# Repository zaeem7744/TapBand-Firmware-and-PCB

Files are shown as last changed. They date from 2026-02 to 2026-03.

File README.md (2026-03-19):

# :watch: TapBand -- MQTT IoT Wearable Device (In Mass Production)







A compact **5cm x 3cm** battery-powered wearable IoT device with MQTT real-time communication, OLED display, WS2812B LEDs, vibration motor, and deep-sleep power optimization. Built for a commercial security application for an Ireland-based startup -- **currently in mass production**.

> See also: [TapBand Web Dashboard](https://github.com/zaeem7744/TapBand-Web-Dashboard)

---

## :camera: PCB Design (Altium Designer)

### Front -- ESP32 Module + OLED Display
Custom-designed compact PCB featuring ESP32 Wi-Fi/BLE module and SSD1306 OLED display.

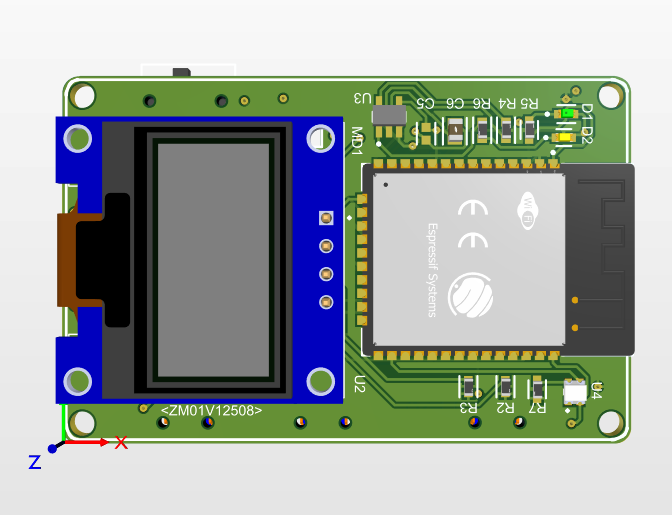
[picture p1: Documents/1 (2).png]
TapBand PCB Front


### Back -- Full Component Layout
Battery connector, USB charging, 4 navigation buttons (SW1-SW4), vibration motor driver, WS2812B LED driver, and SMD power management.

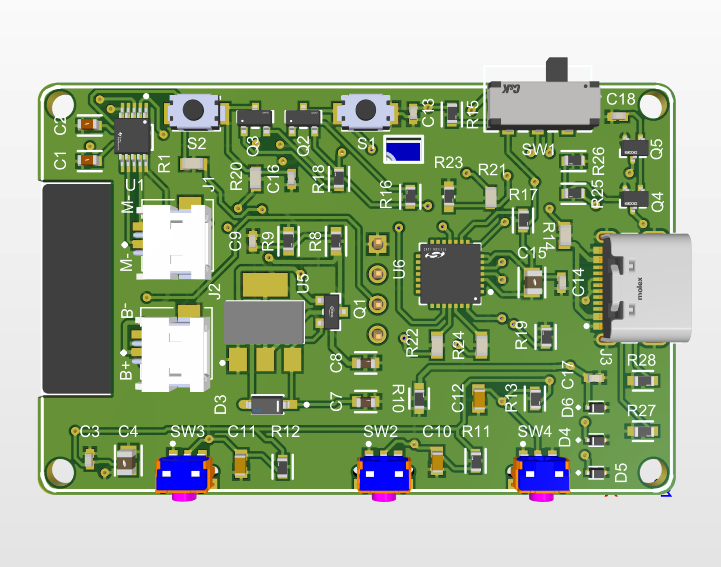
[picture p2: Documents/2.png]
TapBand PCB Back


### PCB Layout -- Altium Designer
Multi-layer PCB routing optimized for compact form factor and RF performance.

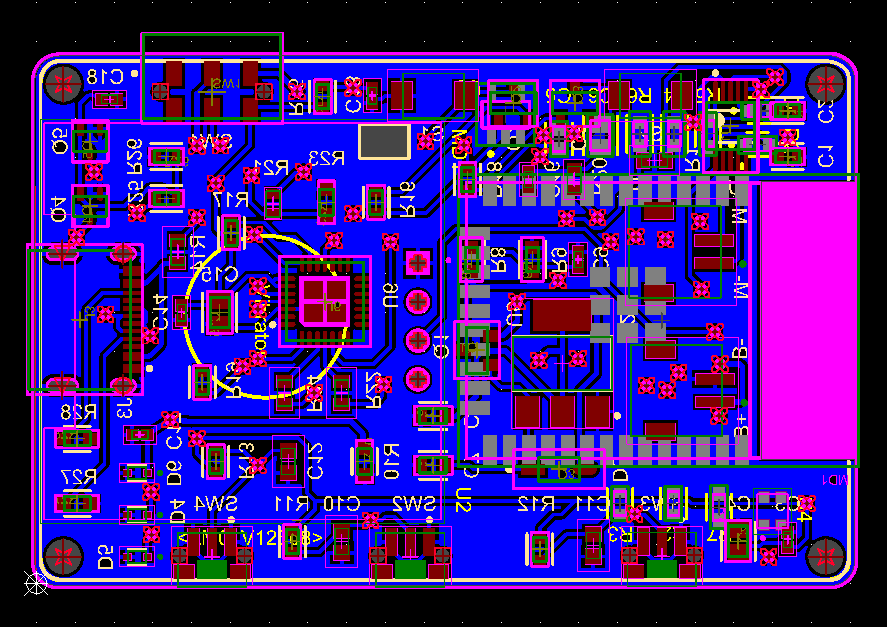
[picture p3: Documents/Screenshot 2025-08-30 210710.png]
PCB Layout


---

## :zap: Key Highlights

- **Ultra-Compact: 5cm x 3cm** -- production-optimized PCB designed in Altium Designer
- **Currently in mass production** for commercial security applications
- **MQTT real-time communication** via HiveMQ Cloud broker
- **Deep-sleep optimization** for extended battery life
- **Wi-Fi provisioning** -- hotspot-based setup, no hardcoded credentials
- **Custom PCB with Gerber files** -- production-ready design
- **Full ecosystem** -- firmware + PCB + web dashboard + Flask backend

---

## :wrench: Features

| Feature | Description |
|---|---|
| **OLED Display** | SSD1306 menu-driven interface with navigation buttons |
| **MQTT Communication** | Bidirectional real-time messaging via HiveMQ Cloud |
| **Deep Sleep** | Aggressive power saving for battery longevity |
| **Wi-Fi Provisioning** | Hotspot-based initial setup |
| **WS2812B LEDs** | Addressable RGB LED indicators for visual alerts |
| **Vibration Motor** | Haptic feedback for notifications |
| **4 Navigation Buttons** | Physical UI for menu navigation and actions |
| **USB Charging** | Micro-USB/USB-C connector for battery charging |
| **Admin Dashboard** | Real-time subscription management via web panel |
| **Flask Backend** | Server-side MQTT relay and device management |

---

## :file_folder: Project Structure

```
TapBand-Firmware-and-PCB/
|-- TapBand_Main/              # Main production firmware
|-- TapBand_Design/            # Altium Designer PCB project files
|-- Documents/                 # PCB renders, screenshots, schematics
|-- MQTT/                      # MQTT communication module
|-- OLED_MQTT/                 # OLED + MQTT integration
|-- OLED_INTERFAACE/           # OLED display driver
|-- WIFI_PROVISIONIG_MQTT_OLED/ # Wi-Fi provisioning system
|-- PowerSave_AlertBand_Test/  # Deep-sleep power profiling
|-- WS2812_Test/               # LED strip testing
|-- Board_Vibrator_Test/       # Vibration motor testing
|-- Sync_Mqtt_Hive/            # HiveMQ broker sync module
+-- Web App/                   # Flask backend + MQTT dashboard
    |-- mqtt_dashboard/        # Real-time MQTT monitoring
    +-- tapband_server/        # Flask backend for device management
```

---

## :hammer_and_wrench: Tech Stack

| Component | Technology |
|---|---|
| **MCU** | ESP32 (Espressif Systems) |
| **Language** | C/C++ (PlatformIO) |
| **Communication** | MQTT (HiveMQ Cloud), Wi-Fi |
| **Display** | SSD1306 OLED (I2C) |
| **LEDs** | WS2812B addressable RGB |
| **PCB Design** | Altium Designer |
| **Backend** | Flask (Python) + MQTT relay |
| **Dashboard** | [React + TypeScript](https://github.com/zaeem7744/TapBand-Web-Dashboard) |
| **Power** | LiPo battery + deep-sleep optimization |

---

## :bust_in_silhouette: Author

**Muhammad Zaeem Sarfraz** -- Electronics & IoT Hardware Engineer

- :link: [LinkedIn](https://www.linkedin.com/in/zaeemsarfraz7744/)
- :email: Zaeem.7744@gmail.com
- :earth_africa: Vaasa, Finland

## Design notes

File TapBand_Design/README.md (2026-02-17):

# TapBand_Design

Altium Designer project for the band’s electronics: MCU, power, haptics, display, and connectors.

## Open
- `TapBand/TapBand.PrjPcb` in Altium Designer

## What’s inside
- Schematics (`*.SchDoc`):
  - Main: ESP32 and core nets
  - I2C_OLED_DRV2605: OLED and haptics driver
  - VOLTAGE_REGULATOR: power tree and battery input
  - USB_UART: programming and debug
  - Menu_Navigators: buttons/encoder
- PCB: `TapBand.PcbDoc`
- Outputs: `Project Outputs for TapBand/` → Gerbers, drills, BOM, pick‑and‑place; plus zipped packs
- Logs: ECO, DRC, compilation logs under `Project Logs for TapBand/`
- CAM: example CAMtastic session in `TapBand/CAM/`

## Fabrication checklist
- Verify board stackup with your fab; ensure soldermask openings on the haptic footprint are correct
- Check mounting and keepouts for the actuator and OLED
- Use the provided pick/place and BOM CSVs; confirm part numbers for the DRV2605 variant and OLED connector pitch

## Notes
- If you change net names or variants, regenerate outputs from the OutJob to keep files consistent

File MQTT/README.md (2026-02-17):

# MQTT

Tiny sketch to sanity‑check Wi‑Fi + MQTT connectivity on ESP32.

## Use
- Open `MQTT.ino`
- Set your Wi‑Fi SSID/password and broker host/port/topic
- Flash and open Serial Monitor (115200). You should see connect logs and a periodic publish every 5s

## Tips
- Use a unique client ID per device to avoid broker kicks
- Public brokers are for testing; for real use, switch to a private/TLS broker and don’t hardcode secrets in source

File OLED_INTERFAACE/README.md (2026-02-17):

# OLED_INTERFAACE

OLED rendering experiments to validate fonts/layout on 128x64 displays.

## Build
- Libraries: Adafruit GFX, Adafruit SSD1306
- I2C: SDA 21, SCL 22, address 0x3C (common); adjust if your module differs

## Tips
- If the screen is blank, try lowering I2C frequency, confirm address with an I2C scanner, and check for adequate 3.3V current

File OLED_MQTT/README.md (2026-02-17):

# OLED_MQTT

Prototype: rotary encoder menu + OLED UI + MQTT publish/subscribe.

## Features
- Home screen with battery and Wi‑Fi indicators; shows last alert for ~8s
- Menu: Assist Mode, Alert Mode, Settings, Back (encoder to navigate, press to select)
- MQTT subscribe to band/alert; publishes ASSIST/ALERT on action

## Build
- Board: ESP32, OLED on I2C (SDA 21, SCL 22, 0x3C)
- Encoder pins: CLK 34, DT 35, SW 32 (INPUT_PULLUP)
- Libraries: Adafruit GFX, Adafruit SSD1306, WiFi, PubSubClient

## Notes
- Replace hardcoded SSID/password with your own before flashing
- For smoother UI, debounce the encoder and avoid heavy blocking delays (a few remain in this prototype)

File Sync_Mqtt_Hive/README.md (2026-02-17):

# Sync_Mqtt_Hive

Prototype for synchronizing with HiveMQ topics.

## Notes
- Edit broker/topic credentials, then verify message round‑trip and latency
- Useful for testing subscription/publish ordering and retained messages

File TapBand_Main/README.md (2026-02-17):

# TapBand_Main

Feature‑complete ESP32 firmware for the band: OLED UI, menu system, Wi‑Fi provisioning via captive portal, MQTT alerts, and haptics through DRV2605.

## Hardware/pins (defaults)
- OLED I2C: SDA 21, SCL 22, addr 0x3C
- Buttons: UP 27, DOWN 34, SELECT 35 (INPUT_PULLUP)
- Vibration: EN 33 (DRV2605 on I2C)
- Battery sense: ADC 19 via divider R1=220k, R2=100k
- Built‑in LED used for alert blink feedback

## Libraries
- Adafruit GFX, Adafruit SSD1306, Adafruit DRV2605
- PubSubClient (MQTT), WiFi, WebServer, Preferences

## Build (Arduino IDE)
1) Board: “ESP32 Dev Module” (or your ESP32 variant)
2) Install libraries above from Library Manager
3) Open `TapBand_Main.ino` and flash; Serial Monitor: 115200 baud
4) If first boot has no Wi‑Fi creds, use Menu → Settings → Wi‑Fi Setup

## Menu map and flow
- Home → shows battery, Wi‑Fi bars, and last alert for ~8s
- Main Menu: Alert Mode, Assist Mode, Normal Mode, Settings, Back
- Settings: Wi‑Fi Setup (starts AP + portal), Reset Wi‑Fi, Back
- In modes, pressing SELECT publishes the corresponding MQTT message and returns Home

## Wi‑Fi provisioning (captive portal)
- When Wi‑Fi Setup is selected, device starts AP TapBand_<DEVICE_ID> and a minimal web server
- Open the root page, submit SSID/password; device stores them in NVS (Preferences) and restarts
- Hotspot auto‑times‑out after 180s (WIFI_HOTSPOT_TIMEOUT)

## MQTT
- Defaults: server broker.hivemq.com, port 1883, topic band/alert (see Config.h)
- Subscribes to band/alert; publishes NORMAL/ALERT/ASSIST depending on mode
- Tip: in production, change to your broker, use TLS, and unique client IDs; consider Last‑Will and retained metadata

## Battery model
- Voltage: Vadc = raw/4095*3.3V; Vbat = Vadc*(R1+R2)/R2 + VOLTAGE_OFFSET
- Percentage mapping clamps between BATTERY_EMPTY (3.7V) and BATTERY_FULL (4.2V). Adjust these and VOLTAGE_OFFSET per your cells/board.

## Haptics
- DRV2605 library 1, INTTRIG mode. Effects are mapped in `Vibration_System.h`:
  - Wi‑Fi connect/disconnect, menu navigate/back/screen change, confirmations, alerts, low battery, hotspot start
- Start with short effects to verify actuator polarity and mounting

## Extending
- New menu items: add labels to Menu_System.cpp, handle in switch, and implement action.
- New MQTT topics: update Config.h and WiFi_MQTT.cpp callback/publish sites.
- UI: tweak Display_Functions.cpp; keep draw calls minimal per frame to avoid flicker.

## Troubleshooting
- “SSD1306 allocation failed”: power/I2C wiring or wrong address
- No MQTT: check Wi‑Fi status, broker reachability, and client.loop() in the main loop
- ADC jumps: add a small RC filter, sample average (already 5x), and re‑tune VOLTAGE_OFFSET

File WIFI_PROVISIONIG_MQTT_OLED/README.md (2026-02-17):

# WIFI_PROVISIONIG_MQTT_OLED

Minimal demo showing captive portal provisioning, MQTT connectivity, and a compact OLED UI.

## What it does
- Shows Home with battery and Wi‑Fi bars
- Main Menu → Settings → Wi‑Fi Setup starts AP TapBand_<ID> and hosts a simple form at “/”
- POST to "/connect" saves SSID/password to Preferences and restarts
- Hotspot timeout: 180s; display shows countdown

## Build
- Board: ESP32 Dev Module
- Libraries: Adafruit GFX, Adafruit SSD1306, WiFi, PubSubClient, WebServer, Preferences
- Pins: SDA 21, SCL 22, Encoder CLK/DT/SW 34/35/32 (if used), OLED 0x3C

## MQTT
- Default: broker.hivemq.com, topic band/alert; change for your broker/security

## Tips
- If the portal doesn’t load, ensure you are connected to the device AP, not a LAN with captive DNS
- After provisioning, the device returns to HOME automatically; use Reset Wi‑Fi to clear creds

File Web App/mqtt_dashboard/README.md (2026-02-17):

# mqtt_dashboard

Flask + MQTT dashboard to manage “shops” and “bands”, visualize online/offline status, and toggle per‑band alerts.

## Stack and layout
- Flask app: `app.py`
- Templates: `templates/index.html`, `templates/shop.html`
- SQLite DB: `bands.db` with tables shops(id, shop_name, start_date, end_date) and bands(id, band_name, shop_id)
- MQTT: paho‑mqtt client thread for subscriptions and control publishing

## Install and run
- Python 3.x
- pip install flask paho-mqtt
- Configure broker in `app.py`:
  - Host/port: mqtt_client.connect(...)
  - TLS CA path: mqtt_client.tls_set("<path-to-ca.crt>")
  - Username/password: mqtt_client.username_pw_set("<user>", "<pass>")
- Initialize DB and start: python app.py → http://localhost:5000

## MQTT topics
- Subscribes: tapband/# and tapband/alerts
- Publishes control: tapband/control/{shop}/{band} with payload "enable" or "disable"
- Device status feed (expected): tapband/{shop}/Band_XXX with JSON payloads like {"uptime": "HH:MM"}
- An offline checker thread marks devices offline if no message for >10s; subscription state updates every 5s

## Pages
- Dashboard “/”: create shops, view subscription window, counts of total/online bands
- Shop “/shop/<id>”: list bands, toggle alert (publishes control topic), add/delete bands

## Notes and tips
- Keep TLS CA path valid for your broker; if you use a public broker without TLS, remove tls_set and change port
- For production: run gunicorn/uwsgi behind a reverse proxy; move credentials to environment variables
- The web UI is intentionally minimal; extend templates for richer views (signal strength, last seen, etc.)

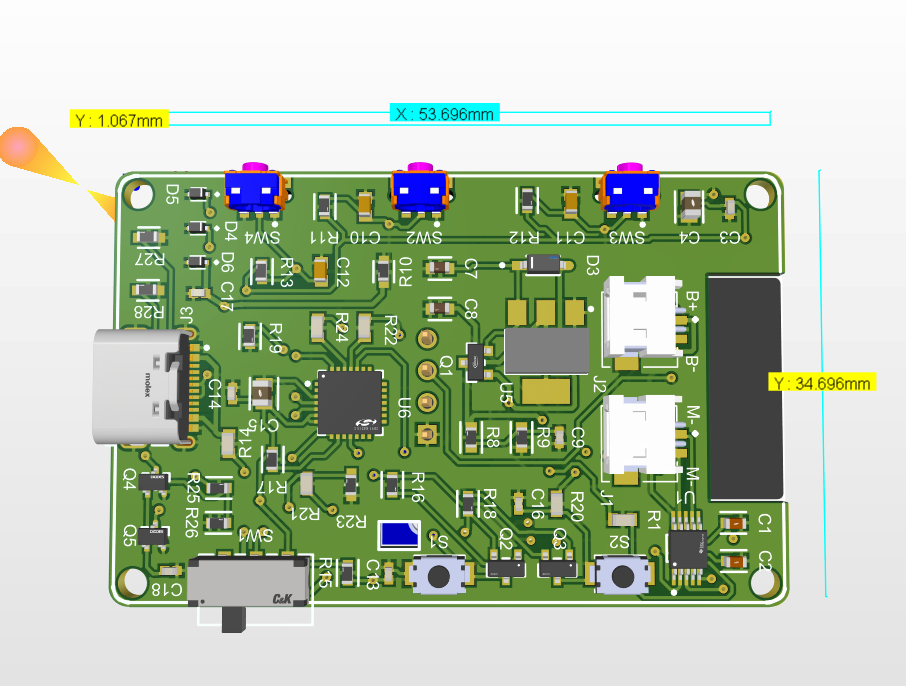
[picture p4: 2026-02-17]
Documents/Screenshot 2025-08-30 212027.png

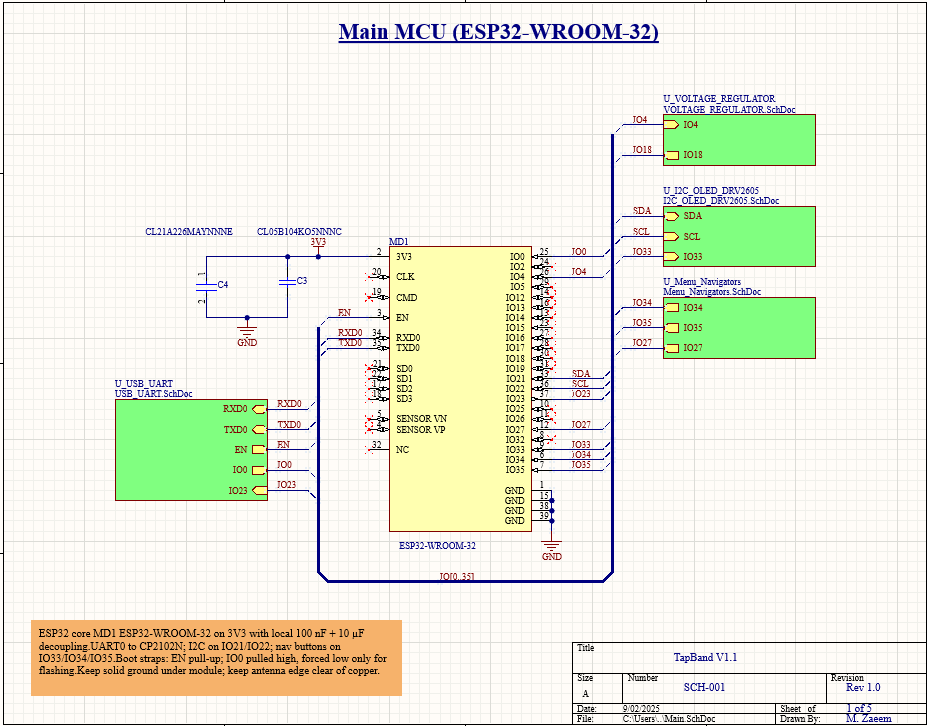
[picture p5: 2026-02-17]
Documents/Screenshot 2025-09-02 193534.png

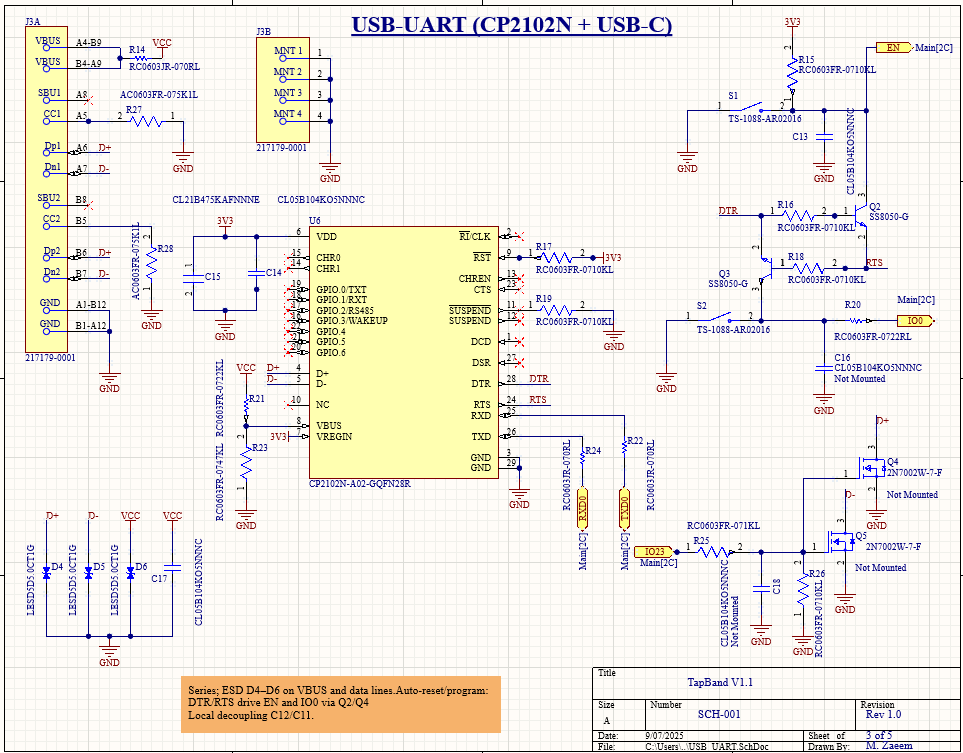
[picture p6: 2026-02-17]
Documents/Screenshot 2025-09-07 011952.png

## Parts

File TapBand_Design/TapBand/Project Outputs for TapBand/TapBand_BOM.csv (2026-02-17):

Comment | Description | Designator | Footprint | Supplier | Supplier Part Number | Quantity
CL10B105KA8NNNC | CAP CER 1UF 25V X7R 0603 | C1, C2 | FP-CL10-IPC_C | LCSC | C29936 | 2
CL05B104KO5NNNC | Chip Capacitor, 100 nF, +/- 10%, 16 V, -55 to 125 degC, 0402 (1005 Metric), RoHS, Tape and Reel | C3, C9, C13, C14, C16, C17, C18 | CAPC1050X55X23ML05T13 | LCSC | C1525 | 7
CL21A226MAYNNNE | CL21 Series 0805 22uF 25V ±20% Tolerance X5R Multilayer Ceramic Chip Capacitor | C4 | FP-CL21-IPC_C | LCSC | C602037 | 1
GRM188R61E475KE11D | Chip Multilayer Ceramic Capacitors for General Purpose, 0603, 4.7uF, X5R, 15%, 10%, 25V | C5 | FP-GRM188-0_15-IPC_C | LCSC | C90057 | 1
CL21B475KAFNNNE | CL21 Series 0805 4.7uF 25V ±10% Tolerance X7R Multilayer Ceramic Chip Capacitor | C6, C15 | FP-CL21-IPC_C | LCSC | C98195 | 2
GRM188R61E106MA73D | Chip Multilayer Ceramic Capacitors for General Purpose, 0603, 10uF, X5R, 15%, 20%, 25V | C7, C8 | FP-GRM188-0_2-MFG | LCSC | C91606 | 2
GRM188R71H104KA93D | Chip Capacitor, 0.1 uF, +/- 10%, 50 V, -55 to 125 degC, 0603 (1608 Metric), RoHS, Tape and Reel | C10, C11, C12 | CAPC1608X90X35ML10T15 | LCSC | C77055 | 3
LTST-C190GKT | LED GREEN CLEAR CHIP SMD | D1 | FP-LTST-C190GKT-MFG | LCSC | C125093 | 1
LTST-C191KSKT | LED YELLOW CLEAR SMD | D2 | FP-LTST-C191KSKT-MFG | LCSC | C125100 | 1
1N5819HW-7-F | DIODE SCHOTTKY 40V 1A SOD123 | D3 | FP-SOD123-IPC_A | LCSC | C82544 | 1
LESD5D5.0CT1G | Transient Voltage Suppressors for ESD Protection | D4, D5, D6 | TVS_LESD5D5.0CT1G | LCSC | C383211 | 3
S2B-ZR-SM4A-TF(LF)(SN) | Connector Header Surface Mount, Right Angle 2 position 0.059 (1.50mm) | J1, J2 | JST_S2B-ZR-SM4A-TF(LF)(SN) | LCSC | C265329 | 2
217179-0001 | CONN RCP USB2.0 TYP C 24P SMD RA | J3 | FP-2171790001-MFG | LCSC | C3197684 | 1
ESP32-WROOM-32 | RX TXRX MOD WIFI SURFACE MOUNT | MD1 | FP-ESP32-WROOM-32-MFG | LCSC | C701343 | 1
IRLML6402TRPBF | MOSFET P-CH 20V 3.7A SOT-23 | Q1 | FP-Micro3-MFG | LCSC | C2593 | 1
SS8050-G | NPN TRANSISTOR 1.5A 40V SOT-23 R | Q2, Q3 | FP-SS8050-G-MFG | LCSC | C164886 | 2
2N7002W-7-F | MOSFET N-CH 60V 115MA SOT323 | Q4, Q5 | FP-SOT323-IPC_C | LCSC | C139444 | 2
RC0603JR-070RL | Chip Resistor, 0 Ohm, +/- 5%, 0.1 W, -55 to 155 degC, 0603 (1608 Metric), RoHS, Tape and Reel | R1, R14, R22, R24 | RESC1608X55X25ML10T15 | LCSC | C95177 | 4
RC0603FR-0710KL | RES 10K OHM 1% 1/10W 0603 | R2, R3, R11, R12, R13, R15, R16, R17, R18, R19, R26 | FP-RC0603-0_55-IPC_C | LCSC | C98220 | 11
AC0603FR-072KL | RES 2kO 1.00% 0.1W 0603 | R4, R6 | FP-AC0603-IPC_B | LCSC | C125933 | 2
AC0603FR-075K1L | RES 5.1KO 1.00% 0.1W 0603 | R5, R7, R27, R28 | FP-AC0603-MFG | LCSC | C125891 | 4
RC0603FR-07200KL | RES SMD 200K OHM 1% 1/10W 0603 | R8, R9 | FP-RC0603-0_55-IPC_B | LCSC | C105574 | 2
AC0603FR-07100KL | RES 100KO 1.00% 0.1W 0603 | R10 | FP-AC0603-MFG | LCSC | C116674 | 1
RC0603FR-0722RL | Chip Resistor, 22 Ohm, +/- 1%, 0.1 W, -55 to 155 degC, 0603 (1608 Metric), RoHS, Tape and Reel | R20 | RESC1608X55X25NL10T15 | LCSC | C107701 | 1
RC0603FR-0722KL | Chip Resistor, 22 KOhm, +/- 1%, 0.1 W, -55 to 155 degC, 0603 (1608 Metric), RoHS, Tape and Reel | R21 | RESC1608X55X25LL10T15 | LCSC | C114065 | 1
RC0603FR-0747KL | RES SMD 47K OHM 1% 1/10W 0603 | R23 | FP-RC0603FR-0747KL-MFG | LCSC | C105579 | 1
RC0603FR-071KL | RES 1K OHM 1% 1/10W 0603 | R25 | FP-RC0603-0_55-IPC_C | LCSC | C22548 | 1
TS-1088-AR02016 | 50mA 4mm 100MÎ© 100,000 Times 12V 160gf 3mm 2mm Round Button Vertical welding SPST SMD Tactile Switches ROHS | S1, S2 | SW_TS-1088-AR02016 | LCSC | C720477 | 2
JS202011JAQN | SWITCH SLIDE DPDT 300MA 6V | SW1 | FP-JS202011JAQN-MFG | LCSC | C221664 | 1
SKRTLAE010 | Side Push Type, 250 V, -40 to 90 degC, 3-Pin SMD, RoHS, Tape and Reel | SW2, SW3, SW4 | ALPS-SKRTLAE010_V | LCSC | C110293 | 3
DRV2605LDGSR | IC MOTOR DRIVER 2V-5.5V 10VSSOP | U1 | FP-DGS0010A-MFG | LCSC | C527464 | 1
DM-OLED096-636 | 0.96â€� 128 X 64 MONOCHROME GRAPHIC OLED DISPLAY MODULE - I2C | U2 | MODULE_DM-OLED096-636 | LCSC | C5248080 | 1
MCP73831T-2ACI/OT | IC CONTROLLR LI-ION 4.2V SOT23-5 | U3 | FP-C04-091-OT-MFG | LCSC | C424093 | 1
WS2812C-2020 | Intelligent control LED integrated light source | U4 | LED_WS2812C-2020 | LCSC | C2976072 | 1
NCP1117ST33T3G | Low-Dropout Positive Fixed Voltage Regulator, 1 A, 3.3 V Output Voltage, 0 to 125 degC, 4-Pin SOT-223 (318H-01), Pb-Free, Tape and Reel | U5 | ONSC-SOT-223-4-318H-01_A_V | LCSC | C26537 | 1
CP2102N-A02-GQFN28R | IC USB TO UART BRIDGE QFN28 | U6 | FP-CP2102N-A02-GQFN28R-MFG | LCSC | C964632 | 1

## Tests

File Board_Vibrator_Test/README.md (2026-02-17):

# Board_Vibrator_Test

Validate the DRV2605 haptic driver and actuator wiring.

## Build
- Board: ESP32
- Libraries: Adafruit DRV2605, Wire
- I2C: SDA 21, SCL 22; ensure 3.3V and GND connected; typical DRV2605 addr 0x5A

## What to look for
- Short clicks/buzzes for different effects; if it feels weak or inverted, re‑mount the actuator or try other effects
- If nothing happens: check I2C wiring, selectLibrary(1), and INTTRIG mode

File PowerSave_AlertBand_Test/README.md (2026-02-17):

# PowerSave_AlertBand_Test

Experiments around lowering power while preserving alert behavior.

## Ideas tested
- Short display update windows, longer sleep between loops
- Minimizing Wi‑Fi duty cycle; reconnect only when needed
- Visual cue on wake, then resume sleep

## Measure
- Use a USB power meter or shunt to compare baseline vs. optimized loops

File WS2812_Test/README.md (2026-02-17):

# WS2812_Test

Quick WS2812/NeoPixel test.

## Build
- Board: ESP32
- Library: Adafruit NeoPixel (if used in the sketch)
- Define LED pin and count for your setup; ensure a proper 5V rail and a level‑shifted data line if the run is long

## Notes
- Add a 330–470Ω series resistor on DIN and a large 5V bulk cap (>1000µF) for stability on long strips

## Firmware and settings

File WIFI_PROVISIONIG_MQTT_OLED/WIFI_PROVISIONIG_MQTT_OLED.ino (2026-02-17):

#include <Wire.h>
#include <Adafruit_GFX.h>
#include <Adafruit_SSD1306.h>
#include <WiFi.h>
#include <PubSubClient.h>
#include <WebServer.h>
#include <Preferences.h>

/* ========== HARDWARE CONFIGURATION ========== */
#define SCREEN_WIDTH 128
#define SCREEN_HEIGHT 64
#define OLED_RESET -1
#define SDA_PIN 21
#define SCL_PIN 22

#define ENCODER_CLK 34
#define ENCODER_DT 35
#define ENCODER_SW 32

Adafruit_SSD1306 display(SCREEN_WIDTH, SCREEN_HEIGHT, &Wire, OLED_RESET);

/* ========== SYSTEM VARIABLES ========== */
// Main menu items
const char* mainMenuItems[] = { "Assist Mode", "Alert Mode", "Settings", "Back" };
const int mainMenuLength = sizeof(mainMenuItems) / sizeof(mainMenuItems[0]);

// Settings menu items
const char* settingsMenuItems[] = { "Wi-Fi Setup", "Reset Wi-Fi", "Back" };
const int settingsMenuLength = sizeof(settingsMenuItems) / sizeof(settingsMenuItems[0]);

enum ScreenState {
  HOME,
  MAIN_MENU,
  ASSIST_MODE,
  ALERT_MODE,
  SETTINGS_MENU,
  WIFI_SETUP_MODE
};

ScreenState currentScreen = HOME;
int currentMenu = 0;  // 0 = main menu, 1 = settings menu
int menuIndex = 0;

// Encoder variables
int currentStateCLK;
int lastStateCLK;
unsigned long lastButtonPress = 0;
bool buttonPressed = false;
unsigned long lastMenuInteraction = 0;

// System status
int batteryLevel = 85;
int wifiStrength = 0;
bool wifiConnected = false;
unsigned long wifiHotspotStartTime = 0;
const unsigned long WIFI_HOTSPOT_TIMEOUT = 180000;  // 3 minutes (180000ms)
bool inHotspotMode = false;

String deviceID = "BAND-001X";
String macAddress = "";

/* ========== WiFi + MQTT CONFIGURATION ========== */
const char* mqtt_server = "broker.hivemq.com";
const int mqtt_port = 1883;
const char* mqtt_topic = "band/alert";

WiFiClient espClient;
PubSubClient client(espClient);
WebServer server(80);
Preferences preferences;
String incomingAlert = "";
unsigned long lastAlertTime = 0;

/* ========== OLED DISPLAY FUNCTIONS ========== */
void drawHomeScreen() {
  display.clearDisplay();
  display.setTextColor(SSD1306_WHITE);

  // Header with battery and WiFi indicators
  display.fillRect(0, 0, SCREEN_WIDTH, 16, SSD1306_BLACK);
  display.drawRect(0, 0, SCREEN_WIDTH, 16, SSD1306_WHITE);

  // Battery indicator
  display.drawRect(2, 4, 30, 8, SSD1306_WHITE);
  display.fillRect(32, 6, 2, 4, SSD1306_WHITE);
  int batteryFill = map(batteryLevel, 0, 100, 0, 28);
  display.fillRect(3, 5, batteryFill, 6, SSD1306_WHITE);
  display.setTextSize(1);
  display.setCursor(38, 4);
  display.print(batteryLevel);
  display.print("%");

  // WiFi indicator
  int wifiX = SCREEN_WIDTH - 25;
  for (int i = 0; i < 4; i++) {
    int barHeight = (i + 1) * 2 + 2;  // Heights: 4,6,8,10 pixels
    int barY = 14 - barHeight;

    if (wifiStrength > i) {
      // Filled bar for active strength
      display.fillRect(wifiX + i * 5, barY, 3, barHeight, SSD1306_WHITE);
    } else {
      // Outline for inactive bars
      display.drawRect(wifiX + i * 5, barY, 3, barHeight, SSD1306_WHITE);
    }
  }


  // Main status text
  display.setTextSize(2);
  display.setCursor(30, 25);

  if (millis() - lastAlertTime < 8000 && incomingAlert.length() > 0) {
    display.print(incomingAlert);
  } else {
    if (wifiConnected) {
      display.print("NORMAL");
    } else {
      display.print("NO WIFI");
    }
  }

  // Footer
  display.setTextSize(1);
  display.setCursor(25, 45);
  display.print("TAP BAND V1.1");

  display.drawLine(0, SCREEN_HEIGHT - 10, SCREEN_WIDTH, SCREEN_HEIGHT - 10, SSD1306_WHITE);
  display.setCursor(0, SCREEN_HEIGHT - 8);
  display.print("Press Button For Menu");

  display.display();
}

void drawWiFiHotspotScreen() {
  display.clearDisplay();
  display.setTextSize(1);
  display.setCursor(5, 5);
  display.println("Wi-Fi Hotspot Active");

  display.setCursor(5, 20);
  display.print("SSID: TapBand_");
  display.println(deviceID.substring(5));

  display.setCursor(5, 35);
  display.print("IP: 192.168.4.1");

  display.setTextSize(1);
  display.setCursor(20, 50);
  display.print("Timeout: ");
  display.print((WIFI_HOTSPOT_TIMEOUT - (millis() - wifiHotspotStartTime)) / 1000);
  display.print("s");

  // Show back option
  //display.setCursor(SCREEN_WIDTH - 30, SCREEN_HEIGHT-8);
  //display.print("BACK");

  display.display();
}

void drawWiFiStatusScreen(const char* status) {
  display.clearDisplay();
  display.setTextSize(1);
  display.setCursor(20, 25);
  display.print(status);
  display.display();
  delay(2000);
  drawHomeScreen();
}

void drawMenuScreen() {
  display.clearDisplay();
  display.setTextSize(1);
  display.setCursor(30, 2);
  display.print(currentMenu == 0 ? "MAIN MENU" : "SETTINGS");
  display.drawLine(0, 12, SCREEN_WIDTH, 12, SSD1306_WHITE);

  int itemHeight = 13;
  int startY = 15;
  int menuLength = currentMenu == 0 ? mainMenuLength : settingsMenuLength;
  const char** menuItems = currentMenu == 0 ? mainMenuItems : settingsMenuItems;

  for (int i = 0; i < menuLength; i++) {
    int y = startY + i * itemHeight;
    if (i == menuIndex) {
      display.fillRect(0, y, SCREEN_WIDTH, itemHeight, SSD1306_WHITE);
      display.setTextColor(SSD1306_BLACK);
    } else {
      display.setTextColor(SSD1306_WHITE);
    }
    display.setCursor(10, y + 3);
    display.print(menuItems[i]);
    if (i == menuIndex) {
      display.drawTriangle(110, y + 3, 120, y + 6, 110, y + 9, SSD1306_BLACK);
    }
  }

  int footerY = startY + menuLength * itemHeight;
  if (footerY < SCREEN_HEIGHT - 12) {
    display.drawLine(0, footerY, SCREEN_WIDTH, footerY, SSD1306_WHITE);
    display.setTextColor(SSD1306_WHITE);
    display.setCursor(25, footerY + 2);
    display.print("Rotate to select");
  }

  display.display();
}

void drawModeScreen(const char* title, const char* instruction) {
  display.clearDisplay();
  display.setTextSize(1);
  display.setCursor(SCREEN_WIDTH / 2 - strlen(title) * 3, 2);
  display.print(title);
  display.drawLine(0, 12, SCREEN_WIDTH, 12, SSD1306_WHITE);

  display.setCursor(SCREEN_WIDTH / 2 - strlen(instruction) * 3, 30);
  display.print(instruction);

  display.drawLine(0, SCREEN_HEIGHT - 10, SCREEN_WIDTH, SCREEN_HEIGHT - 10, SSD1306_WHITE);
  display.setCursor(30, SCREEN_HEIGHT - 7);
  display.print("Press To confirm");
  display.setCursor(SCREEN_WIDTH - 30, SCREEN_HEIGHT - 7);
  // display.print("BACK");

  display.display();
}

/* ========== WIFI MANAGEMENT FUNCTIONS ========== */
void startWiFiHotspot() {
  WiFi.mode(WIFI_AP);
  String apSSID = "TapBand_" + deviceID.substring(5);
  WiFi.softAP(apSSID.c_str());
  macAddress = WiFi.softAPmacAddress();

  server.on("/", HTTP_GET, []() {
    String html = "<!DOCTYPE html><html><head><title>TapBand Wi-Fi Setup</title>"
                  "<meta name=\"viewport\" content=\"width=device-width, initial-scale=1\">"
                  "<style>"
                  "body {font-family: Arial, sans-serif; background-color: #f8f9fa; color: #333; max-width: 500px; margin: 0 auto; padding: 20px;}"
                  ".container {background: white; border-radius: 8px; padding: 20px; box-shadow: 0 2px 10px rgba(0,0,0,0.1);}"
                  "h2 {color: #4a6fa5; text-align: center;}"
                  ".device-id {background: #4a6fa5; color: white; padding: 10px; border-radius: 5px; text-align: center; margin-bottom: 20px;}"
                  "input[type=text], input[type=password] {width: 100%; padding: 12px; margin: 8px 0; display: inline-block; border: 1px solid #ccc; border-radius: 4px; box-sizing: border-box;}"
                  "button {background-color: #4a6fa5; color: white; padding: 14px 20px; margin: 8px 0; border: none; border-radius: 4px; cursor: pointer; width: 100%; font-size: 16px;}"
                  "button:hover {background-color: #3a5a8f;}"
                  ".loader {border: 4px solid #f3f3f3; border-top: 4px solid #4a6fa5; border-radius: 50%; width: 30px; height: 30px; animation: spin 1s linear infinite; margin: 20px auto;}"
                  "@keyframes spin {0% { transform: rotate(0deg); } 100% { transform: rotate(360deg); }}"
                  "</style></head><body>"
                  "<div class=\"container\">"
                  "<div class=\"device-id\">Band ID: "
                  + deviceID + "<br>MAC: " + macAddress + "</div>"
                                                          "<h2>Wi-Fi Setup</h2>"
                                                          "<form id=\"wifiForm\">"
                                                          "<label for=\"ssid\">Network Name (SSID)</label>"
                                                          "<input type=\"text\" id=\"ssid\" name=\"ssid\" placeholder=\"Enter Wi-Fi name\" required>"
                                                          "<label for=\"password\">Password</label>"
                                                          "<input type=\"password\" id=\"password\" name=\"password\" placeholder=\"Enter Wi-Fi password\">"
                                                          "<button type=\"submit\">Connect</button>"
                                                          "</form>"
                                                          "<div id=\"loading\" style=\"display:none;\"><div class=\"loader\"></div><p>Connecting...</p></div>"
                                                          "<script>"
                                                          "document.getElementById('wifiForm').addEventListener('submit', function(e) {"
                                                          "e.preventDefault();"
                                                          "document.getElementById('wifiForm').style.display = 'none';"
                                                          "document.getElementById('loading').style.display = 'block';"
                                                          "fetch('/connect', {"
                                                          "method: 'POST',"
                                                          "headers: {'Content-Type': 'application/x-www-form-urlencoded',},"
                                                          "body: 'ssid=' + encodeURIComponent(document.getElementById('ssid').value) + "
                                                          "'&password=' + encodeURIComponent(document.getElementById('password').value)"
                                                          "}).then(response => response.text()).then(data => {"
                                                          "document.getElementById('loading').innerHTML = '<p>' + data + '</p>';"
                                                          "if(data.includes('Success')) { setTimeout(() => { window.location.href = '/'; }, 2000); }"
                                                          "});"
                                                          "});"
                                                          "</script></div></body></html>";
    server.send(200, "text/html", html);
  });

  server.on("/connect", HTTP_POST, []() {
    String ssid = server.arg("ssid");
    String password = server.arg("password");

    preferences.begin("wifi", false);
    preferences.putString("ssid", ssid);
    preferences.putString("password", password);
    preferences.end();

    server.send(200, "text/plain", "Success! Device will restart and attempt to connect.");
    delay(1000);
    ESP.restart();
  });

  server.begin();
  wifiHotspotStartTime = millis();
  inHotspotMode = true;
  currentScreen = WIFI_SETUP_MODE;
}

void stopWiFiHotspot() {
  WiFi.softAPdisconnect(true);
  server.close();
  inHotspotMode = false;
  currentScreen = HOME;
  drawHomeScreen();
}

void resetWiFiCredentials() {
  if (WiFi.status() != WL_CONNECTED) {
    display.setCursor(8, 30);
    drawWiFiStatusScreen("No WiFi Connected");
    return;
  }

  preferences.begin("wifi", false);
  preferences.remove("ssid");
  preferences.remove("password");
  preferences.end();

  WiFi.disconnect();
  wifiConnected = false;
  drawWiFiStatusScreen("Wi-Fi Deleted!");
}

void checkWiFiConnection() {
  static unsigned long lastCheck = 0;
  if (millis() - lastCheck < 10000) return;  // Check every 10 seconds
  lastCheck = millis();

  if (WiFi.status() == WL_CONNECTED) {
    int rssi = WiFi.RSSI();
    Serial.print("RSSI: ");
    Serial.println(rssi);

    // Adjusted thresholds based on your actual readings
    if (rssi > -30) {
      wifiStrength = 4;  // Excellent (-29 to 0)
      Serial.println("4 bars - Excellent");
    } else if (rssi > -50) {
      wifiStrength = 3;  // Good (-49 to -30)
      Serial.println("3 bars - Good");
    } else if (rssi > -65) {
      wifiStrength = 2;  // Fair (-64 to -50)
      Serial.println("2 bars - Fair");
    } else if (rssi > -80) {
      wifiStrength = 1;  // Weak (-79 to -65)
      Serial.println("1 bar - Weak");
    } else {
      wifiStrength = 0;  // Very weak/No signal (< -80)
      Serial.println("0 bars - No signal");
    }

    if (!wifiConnected) {
      wifiConnected = true;
      drawHomeScreen();  // Force redraw when first connecting
    }
  } else {
    wifiConnected = false;
    wifiStrength = 0;
  }
}

/* ========== MQTT FUNCTIONS ========== */
void reconnectMQTT() {
  while (!client.connected()) {
    Serial.print("Connecting to MQTT...");
    if (client.connect(deviceID.c_str())) {
      Serial.println("connected");
      client.subscribe(mqtt_topic);
    } else {
      Serial.print(" failed, rc=");
      Serial.print(client.state());
      delay(2000);
    }
  }
}

void mqttCallback(char* topic, byte* payload, unsigned int length) {
  String message = "";
  for (unsigned int i = 0; i < length; i++) {
    message += (char)payload[i];
  }

  if (String(topic) == mqtt_topic && (message == "ASSIST" || message == "ALERT")) {
    incomingAlert = message;
    lastAlertTime = millis();

    // Visual feedback for alert
    for (int i = 0; i < 5; i++) {
      digitalWrite(LED_BUILTIN, HIGH);
      delay(300);
      digitalWrite(LED_BUILTIN, LOW);
      delay(300);
    }

    drawHomeScreen();
  }
}

/* ========== ENCODER & MENU FUNCTIONS ========== */
void handleButtonPress() {
  switch (currentScreen) {
    case HOME:
      currentScreen = MAIN_MENU;
      currentMenu = 0;
      menuIndex = 0;
      lastMenuInteraction = millis();
      drawMenuScreen();
      break;

    case MAIN_MENU:
      handleMainMenuSelection();
      break;

    case SETTINGS_MENU:
      handleSettingsMenuSelection();
      break;

    case ASSIST_MODE:
      sendAssistRequest();
      currentScreen = HOME;
      drawHomeScreen();
      break;

    case ALERT_MODE:
      sendAlertSignal();
      currentScreen = HOME;
      drawHomeScreen();
      break;

    case WIFI_SETUP_MODE:
      // Manual back from WiFi setup
      stopWiFiHotspot();
      break;
  }
}

void handleMainMenuSelection() {
  switch (menuIndex) {
    case 0:  // Assist Mode
      currentScreen = ASSIST_MODE;
      drawModeScreen("ASSIST MODE", "Press To Request Help");
      break;
    case 1:  // Alert Mode
      currentScreen = ALERT_MODE;
      drawModeScreen("ALERT MODE", "Press To Send Alert");
      break;
    case 2:  // Settings
      currentScreen = SETTINGS_MENU;
      currentMenu = 1;
      menuIndex = 0;
      drawMenuScreen();
      break;
    case 3:  // Back
      currentScreen = HOME;
      drawHomeScreen();
      break;
  }
}

void handleSettingsMenuSelection() {
  switch (menuIndex) {
    case 0:  // Wi-Fi Setup
      startWiFiHotspot();
      break;
    case 1:  // Reset Wi-Fi
      resetWiFiCredentials();
      currentScreen = HOME;
      break;
    case 2:  // Back
      currentScreen = MAIN_MENU;
      currentMenu = 0;
      menuIndex = 2;  // Return to Settings option in main menu
      drawMenuScreen();
      break;
  }
}

/* ========== SETUP & LOOP ========== */
void setup() {
  Serial.begin(115200);
  pinMode(LED_BUILTIN, OUTPUT);

  // Encoder setup
  pinMode(ENCODER_CLK, INPUT_PULLUP);
  pinMode(ENCODER_DT, INPUT_PULLUP);
  pinMode(ENCODER_SW, INPUT_PULLUP);
  lastStateCLK = digitalRead(ENCODER_CLK);

  // Display setup
  Wire.begin(SDA_PIN, SCL_PIN);
  if (!display.begin(SSD1306_SWITCHCAPVCC, 0x3C)) {
    Serial.println(F("SSD1306 allocation failed"));
    for (;;)
      ;
  }
  display.clearDisplay();
  display.display();
  delay(100);

  // Load WiFi credentials
  preferences.begin("wifi", true);
  String ssid = preferences.getString("ssid", "");
  String password = preferences.getString("password", "");
  preferences.end();

  if (ssid.length() > 0) {
    WiFi.begin(ssid.c_str(), password.c_str());
    Serial.print("Connecting to WiFi");
    unsigned long startTime = millis();
    while (WiFi.status() != WL_CONNECTED && millis() - startTime < 10000) {
      delay(500);
      Serial.print(".");
    }

    if (WiFi.status() == WL_CONNECTED) {
      wifiConnected = true;
      macAddress = WiFi.macAddress();
      Serial.println(" connected!");
    } else {
      Serial.println(" failed!");
    }
  } else {
    Serial.println("No WiFi credentials stored");
  }

  // MQTT setup
  client.setServer(mqtt_server, mqtt_port);
  client.setCallback(mqttCallback);

  drawHomeScreen();
}

void loop() {
  // Handle WiFi hotspot timeout
  if (inHotspotMode && millis() - wifiHotspotStartTime > WIFI_HOTSPOT_TIMEOUT) {
    stopWiFiHotspot();
    drawWiFiStatusScreen("Hotspot Timeout");
  }

  // Handle WiFi connection status
  checkWiFiConnection();

  // Handle MQTT
  if (wifiConnected && !inHotspotMode) {
    if (!client.connected()) {
      reconnectMQTT();
    }
    client.loop();
  }

  // Handle encoder rotation
  currentStateCLK = digitalRead(ENCODER_CLK);
  if (currentStateCLK != lastStateCLK && currentStateCLK == HIGH) {
    if (currentScreen == MAIN_MENU || currentScreen == SETTINGS_MENU || currentScreen == ASSIST_MODE || currentScreen == ALERT_MODE) {
      lastMenuInteraction = millis();

      // Determine which direction the encoder is rotating
      if (digitalRead(ENCODER_DT) != currentStateCLK) {
        // Clockwise rotation
        menuIndex++;
      } else {
        // Counter-clockwise rotation
        menuIndex--;
      }

      // Constrain menu index based on current menu
      if (currentScreen == MAIN_MENU) {
        menuIndex = constrain(menuIndex, 0, mainMenuLength - 1);
      } else if (currentScreen == SETTINGS_MENU) {
        menuIndex = constrain(menuIndex, 0, settingsMenuLength - 1);
      }

      // Redraw menu if needed
      if (currentScreen == MAIN_MENU || currentScreen == SETTINGS_MENU) {
        drawMenuScreen();
      }
    }
  }
  lastStateCLK = currentStateCLK;

  // Handle encoder button press
  if (digitalRead(ENCODER_SW) == LOW) {
    if (millis() - lastButtonPress > 250 && !buttonPressed) {
      buttonPressed = true;
      lastButtonPress = millis();
      handleButtonPress();
      if (currentScreen != HOME) lastMenuInteraction = millis();
    }
  } else {
    buttonPressed = false;
  }

  // Handle menu timeout (return to home after inactivity) - except in WiFi setup mode
  if (currentScreen != HOME && currentScreen != WIFI_SETUP_MODE && millis() - lastMenuInteraction > 10000) {
    currentScreen = HOME;
    drawHomeScreen();
  }

  // Handle web server requests in hotspot mode
  if (inHotspotMode) {
    server.handleClient();
    // Update the display every second
    static unsigned long lastDisplayUpdate = 0;
    if (millis() - lastDisplayUpdate > 1000) {
      drawWiFiHotspotScreen();
      lastDisplayUpdate = millis();
    }
  }
}

/* ========== APPLICATION FUNCTIONS ========== */
void sendAssistRequest() {
  if (client.connected()) {
    client.publish(mqtt_topic, "ASSIST");
    display.clearDisplay();
    display.setTextSize(1);
    display.setCursor(8, 30);
    display.print("ASSIST REQUEST SENT");
    display.display();
    delay(1000);
  } else {
    display.clearDisplay();
    display.setTextSize(1);
    display.setCursor(8, 30);
    display.print("NO WIFI CONNECTION");
    display.display();
    delay(1000);
  }
}

void sendAlertSignal() {
  if (client.connected()) {
    client.publish(mqtt_topic, "ALERT");
    display.clearDisplay();
    display.setTextSize(1);
    display.setCursor(8, 30);
    display.print("ALERT REQUEST SENT");
    display.display();
    delay(1000);
  } else {
    display.clearDisplay();
    display.setTextSize(1);
    display.setCursor(8, 30);
    display.print("NO WIFI CONNECTION");
    display.display();
    delay(1000);
  }
}

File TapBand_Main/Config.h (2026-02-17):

#ifndef CONFIG_H
#define CONFIG_H

#include <Arduino.h>
#include <Wire.h>
#include <Adafruit_GFX.h>
#include <Adafruit_SSD1306.h>
#include <WiFi.h>
#include <PubSubClient.h>
#include <WebServer.h>
#include <Preferences.h>

/* Hardware Configuration */
#define SCREEN_WIDTH 128
#define SCREEN_HEIGHT 64
#define OLED_RESET -1
#define SDA_PIN 21
#define SCL_PIN 22
#define VIBRATOR_EN_PIN 33

// ========================
// BATTERY CONFIG
// ========================
#define BATTERY_ADC_PIN 19
#define R1 220000.0  // 220k resistor
#define R2 100000.0  // 100k resistor
#define BATTERY_FULL 4.2
#define BATTERY_EMPTY 3.7
#define VOLTAGE_OFFSET 0.02
#define ADC_REF_VOLTAGE 3.3
#define ADC_RESOLUTION 4095.0

// ========================
// WIFI CONFIG 
// ========================
#define WIFI_RSSI_MAX -50  // Best signal
#define WIFI_RSSI_MIN -100  // Weakest usable signal
/* System Constants */
#define WIFI_HOTSPOT_TIMEOUT 180000  // 3 minutes
#define MQTT_SERVER "broker.hivemq.com"
#define MQTT_PORT 1883
#define MQTT_TOPIC "band/alert"
#define BATTERY_PIN 19        // Analog pin for battery voltage
#define BATTERY_READ_INTERVAL 10000  // 10 seconds
#define DEVICE_ID "BAND-001X"  // Unified device ID
/* Screen States */
enum ScreenState {
  HOME,
  MAIN_MENU,
  ALERT_MODE,
  ASSIST_MODE,
  NORMAL_MODE,
  SETTINGS_MENU,
  WIFI_SETUP_MODE
};

#endif

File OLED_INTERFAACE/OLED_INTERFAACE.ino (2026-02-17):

#include <Wire.h>
#include <Adafruit_GFX.h>
#include <Adafruit_SSD1306.h>

/* ========== HARDWARE CONFIGURATION ========== */
// Display settings
#define SCREEN_WIDTH 128
#define SCREEN_HEIGHT 64
#define OLED_RESET    -1
#define SDA_PIN 5
#define SCL_PIN 6

// Rotary Encoder with ESP32-C6 compatible pins
#define ENCODER_CLK 34 // CLK pin
#define ENCODER_DT  35  // DT pin
#define ENCODER_SW  32  // Switch pin

Adafruit_SSD1306 display(SCREEN_WIDTH, SCREEN_HEIGHT, &Wire, OLED_RESET);

/* ========== SYSTEM VARIABLES ========== */
// Menu configuration
const char* menuItems[] = { "Assist Mode", "Alert Mode", "Settings", "Back" };
const int menuLength = sizeof(menuItems) / sizeof(menuItems[0]);

enum ScreenState { HOME, MENU, ASSIST_MODE, ALERT_MODE, SETTINGS_MODE };
ScreenState currentScreen = HOME;
int menuIndex = 0;

// Rotary encoder variables
int counter = 0;
int currentStateCLK;
int lastStateCLK;
unsigned long lastButtonPress = 0;
bool buttonPressed = false;

// Status indicators
int batteryLevel = 85;
int wifiStrength = 3; // 0-3 scale

/* ========== MAIN SETUP ========== */
void setup() {
  // Initialize Serial
  Serial.begin(115200);
  while(!Serial); // Wait for serial connection on native USB
  
  // Set encoder pins as inputs with internal pullups
  pinMode(ENCODER_CLK, INPUT_PULLUP);
  pinMode(ENCODER_DT, INPUT_PULLUP);
  pinMode(ENCODER_SW, INPUT_PULLUP);
  
  // Read the initial state of CLK
  lastStateCLK = digitalRead(ENCODER_CLK);
  
  // Initialize display
  Wire.begin(SDA_PIN, SCL_PIN);
  if(!display.begin(SSD1306_SWITCHCAPVCC, 0x3C)) {
    Serial.println(F("SSD1306 allocation failed"));
    for(;;);
  }
  
  // Initial display setup
  display.clearDisplay();
  display.display();
  delay(100); // Display stabilization
  
  // Draw initial screen
  drawHomeScreen();
}

/* ========== MAIN LOOP ========== */
void loop() {
  // Read the current state of CLK
  currentStateCLK = digitalRead(ENCODER_CLK);
  
  // Handle rotary encoder rotation
  if (currentStateCLK != lastStateCLK && currentStateCLK == HIGH) {
    // Only process rotation when in menu screens
    if (currentScreen == MENU || currentScreen == ASSIST_MODE || 
        currentScreen == ALERT_MODE || currentScreen == SETTINGS_MODE) {
      
      // Determine direction
      if (digitalRead(ENCODER_DT) != currentStateCLK) {
        // Counter-clockwise
        menuIndex = constrain(menuIndex + 1, 0, menuLength - 1);
      } else {
        // Clockwise
        menuIndex = constrain(menuIndex - 1, 0, menuLength - 1);
      }
      
      // Update menu display if in menu
      if (currentScreen == MENU) {
        drawMenuScreen();
      }
    }
  }
  lastStateCLK = currentStateCLK;

  // Handle button press
  if (digitalRead(ENCODER_SW) == LOW) {
    // Debounce check
    if (millis() - lastButtonPress > 250 && !buttonPressed) {
      buttonPressed = true;
      lastButtonPress = millis();
      
      handleButtonPress();
    }
  } else {
    buttonPressed = false;
  }

  // Add any periodic checks here if needed
}

/* ========== BUTTON PRESS HANDLER ========== */
void handleButtonPress() {
  switch (currentScreen) {
    case HOME:
      // Enter menu from home screen
      currentScreen = MENU;
      menuIndex = 0;
      drawMenuScreen();
      break;
      
    case MENU:
      // Handle menu selection
      handleMenuSelection(menuIndex);
      break;
      
    case ASSIST_MODE:
      sendAssistRequest();
      currentScreen = HOME;
      drawHomeScreen();
      break;
      
    case ALERT_MODE:
      sendAlertSignal();
      currentScreen = HOME;
      drawHomeScreen();
      break;
      
    case SETTINGS_MODE:
      currentScreen = MENU;
      drawMenuScreen();
      break;
  }
}

/* ========== MENU FUNCTIONS ========== */
void handleMenuSelection(int index) {
  switch (index) {
    case 0: // Assist Mode
      currentScreen = ASSIST_MODE;
      drawModeScreen("ASSIST MODE", "Press To Request Help");
      break;
    case 1: // Alert Mode
      currentScreen = ALERT_MODE;
      drawModeScreen("ALERT MODE", "Press To Send Alert");
      break;
    case 2: // Settings
      currentScreen = SETTINGS_MODE;
      handleSettings();
      break;
    case 3: // Back
      currentScreen = HOME;
      drawHomeScreen();
      break;
  }
}

/* ========== DISPLAY FUNCTIONS ========== */
void drawHomeScreen() {
  display.clearDisplay();
  
  // Set text properties
  display.setTextColor(SSD1306_WHITE);
  
  // Status bar
  display.fillRect(0, 0, SCREEN_WIDTH, 16, SSD1306_BLACK);
  display.drawRect(0, 0, SCREEN_WIDTH, 16, SSD1306_WHITE);
  
  // Battery indicator
  display.drawRect(2, 4, 30, 8, SSD1306_WHITE);
  display.fillRect(32, 6, 2, 4, SSD1306_WHITE);
  int batteryFill = map(batteryLevel, 0, 100, 0, 28);
  display.fillRect(3, 5, batteryFill, 6, SSD1306_WHITE);
  display.setTextSize(1);
  display.setCursor(38, 4);
  display.print(batteryLevel);
  display.print("%");
  
  // WiFi indicator
  int wifiX = SCREEN_WIDTH - 25;
  for (int i = 0; i < 3; i++) {
    if (wifiStrength > i) {
      display.fillRect(wifiX + i*6, 12 - i*3, 4, i*3 + 4, SSD1306_WHITE);
    } else {
      display.drawRect(wifiX + i*6, 12 - i*3, 4, i*3 + 4, SSD1306_WHITE);
    }
  }
  
  // Main content
  display.setTextSize(2);
  display.setCursor(30, 25);
  display.print("NORMAL");
  
  // Version info
  display.setTextSize(1);
  display.setCursor(25, 45);
  display.print("TAP BAND V1.1");
  
  // Footer instruction
  display.drawLine(0, SCREEN_HEIGHT-10, SCREEN_WIDTH, SCREEN_HEIGHT-10, SSD1306_WHITE);
  display.setCursor(0, SCREEN_HEIGHT-8);
  display.print("Press Button For Menu");
  
  display.display();
}

void drawMenuScreen() {
  display.clearDisplay();
  
  // Header
  display.setTextSize(1);
  display.setCursor(30, 2);
  display.print("MENU OPTIONS");
  display.drawLine(0, 12, SCREEN_WIDTH, 12, SSD1306_WHITE);
  
  // Menu items
  int itemHeight = 13;
  int startY = 15;
  
  for (int i = 0; i < menuLength; i++) {
    int y = startY + i * itemHeight;
    
    if (i == menuIndex) {
      display.fillRect(0, y, SCREEN_WIDTH, itemHeight, SSD1306_WHITE);
      display.setTextColor(SSD1306_BLACK);
    } else {
      display.setTextColor(SSD1306_WHITE);
    }
    
    display.setCursor(10, y+3);
    display.print(menuItems[i]);
    
    // Selection indicator
    if (i == menuIndex) {
      display.drawTriangle(110, y+3, 120, y+6, 110, y+9, SSD1306_BLACK);
    }
  }
  
  // Footer
  int footerY = startY + menuLength * itemHeight;
  if (footerY < SCREEN_HEIGHT - 12) {
    display.drawLine(0, footerY, SCREEN_WIDTH, footerY, SSD1306_WHITE);
    display.setTextColor(SSD1306_WHITE);
    display.setCursor(25, footerY + 2);
    display.print("Rotate to select");
  }
  
  display.display();
}
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

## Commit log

2026-03-19 Update README with comprehensive project documentation and PCB images
2026-03-19 Remove sensitive document: Documents/BOM_from_image.xlsx
    [BOM_from_image.xlsx]
2026-03-19 Remove sensitive document: Documents/Receivver schematic.pdf
2026-03-19 Remove sensitive document: Documents/Schematic_ESP32-Tutorial_2025-08-12.pdf
